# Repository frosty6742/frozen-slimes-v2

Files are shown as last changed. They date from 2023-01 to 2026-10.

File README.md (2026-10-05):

# Frozen Slimes V2

Contact: artemis8615

Check out the [Discord](https://discord.gg/vhHEsKjWGV)

This project uses a Wemo D1 mini, mpu6050, bmi160 or bno085s, and a TP4056 charger. On my personal slimes I wanted to use a 18650 batteries due to the longer battery life and how easy they are to get. 

This is the second version of the case with a hotswappable 18650, strap slots build into the pcb and a much improved pcb design. 

This will now also support mpu6050s, bmis160s, and BNO085s all on one pcb with toggles. 

Tested:
- mpu6050 = yes
- bmi160 = yes
- BNO085s = yes

[Build Tutorial](https://youtu.be/H9HIH2EkDvM?si=KdWcgcjPbuMS_1uO)

[Offical Component Guide](https://docs.slimevr.dev/diy/components-guide.html)

## Index
- [Components](#Components)
- [PCB](#PCB)
- [Cases](#Cases)
- [Assembly](#Assembly)
- [Flashing Firmware](#Flashing-firmware)
- [Links](#Links)
- [Community Builds](#Community-Builds)

### Components   
- [TP4056](https://www.amazon.com/HiLetgo-Lithium-Battery-Charging-Protect/dp/B00LTQU2RK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)
- [Wemos D1 Mini](https://www.amazon.com/Organizer-ESP8266-Internet-Development-Compatible/dp/B081PX9YFV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)
- [2in straps](https://www.amazon.com/gp/product/B0C42S3HQC/ref=ox_sc_act_title_1?smid=A29WFRG6NP7W74&psc=1)
- [IMU docs](https://docs.slimevr.dev/diy/components-guide.html)
    - [MPU6050](https://www.amazon.com/MPU-6050-Accelerometer-Gyroscope-Converter-Compatible/dp/B08TH9NH55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)  
    - [BMI160](https://www.amazon.com/UMLIFE-GY-BMI160-Accelerometer-Gyroscope-Acceleration/dp/B09BQTP8SN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)
- [Switch](https://docs.slimevr.dev/diy/components-guide.htmll)
    - [SS22F32](https://www.amazon.com/uxcell-Vertical-Switch-Terminals-Latching/dp/B07GSGJ6DM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)
- [Battery](https://docs.slimevr.dev/diy/components-guide.html)
    - [18650](https://www.amazon.com/s?k=18650&crid=2H65KICLJGU4U&sprefix=18650%2Caps%2C301&ref=nb_sb_noss_1)
- [1n5817 Diode](https://www.amazon.com/100-Pieces-1N5817-Schottky-Rectifier/dp/B079KDQQPD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)
- [180k Resistor](https://www.amazon.com/EDGELEC-Resistor-Tolerance-Resistance-Optional/dp/B07HDFCNXB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)
- [18650 Battery Solderable Holder](https://www.amazon.com/dp/B09N76T4GL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)

### PCB 

This PCB lets every component be soldered on without any extra wires. This includes the diodes and resistor for battery sense and protected charging. 

To order PCBS go to a website like https://cart.jlcpcb.com/quote upload the gerber file zip file and select quanity and color and order. It should autoselect all the other correct options when you upload the gerber file. 

PCB 

PCB 

PCB 



### Cases
Read the cases documentation in [Case STLs](https://github.com/frosty6742/frozen-slimes-v2/tree/main/Case%20STLs)

### Assembly 
Steps 
- [ ] Solder charge board to PCB
- [ ] Solder mpu to PCB 
- [ ] Solder pins from wemo D1 to wemo, set through holes on PCB and solder the pins on the backside of the PCB

- [ ] Add 180K resitor and diodes in the same orientation as the picture 
- [ ] Bridge correct pads to chose imu (for a BNO solder both bridges under its label, for BMI the one bridge under its label, for the mpu6050 no bridges) 
- [ ] Solder on battery holder
- [ ] Solder on switch

- [ ] Check connections with multimeter for contunity 

- [ ] Feel free to reach out to me with any questions 

### Flashing firmware 
Make sure to install the slime vr server with drivers first. 

- [ ] Use this online [firmware flasher](https://slimevr-firmware.bscotch.ca/) with the latest version of main and wemosd1mini.

Make sure to chose the correct imu and orientation. 



BNO/MPU Instructions
- [ ] Orientation:

rotation

BMI Specific Instructions:

- [ ] Orientation:

221204855-9bce6008-605c-4c25-83e0-810afc768479

- [ ] [Calibrate](https://github.com/SlimeVR/SlimeVR-Tracker-ESP?files=1#bmi160) bmis for first use

If the slime vr drivers arent working for you:
- [ ] Uninstall the drivers from device manager 
- [ ] Extract and install [this CH340 driver](https://www.wemos.cc/en/latest/ch340_driver.html)
- [ ] Flash the trackers

### Links
Resources:
- [The Docs (SlimeVR Documentation)](https://docs.slimevr.dev/)
- [Github Repository SlimeVR](https://github.com/SlimeVR/)
- [SlimeVR Discord](https://discord.gg/SlimeVR)

### Community Builds
I love seeing everyone building and using my pcbs, send in your photos if you want them featured!

227595175-0b3c58bc-bebe-40f4-a213-303ace0f15fe



227594965-319fff3d-ec7c-4dd1-b06a-6c97975d8db4





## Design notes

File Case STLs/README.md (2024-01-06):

### Cases

There are a few diffrent cases that have been created. 

I made the two that are listed below but you can also find a variety of other cases and extensions in the #community-cases channel in the discord. 

#V2.1 Snap Case
This case is designed to printed easily. The two halves just snap over the pcb.

This is still in testing and can be found in the discord [here](https://discord.com/channels/1032474370628653137/1032474371257810986/1186046022753992724)

#V2 Case
This is the original case that I created for the project but some people have trouble printing it and putting it together. 

CAD [here](https://a360.co/42u5nMa).

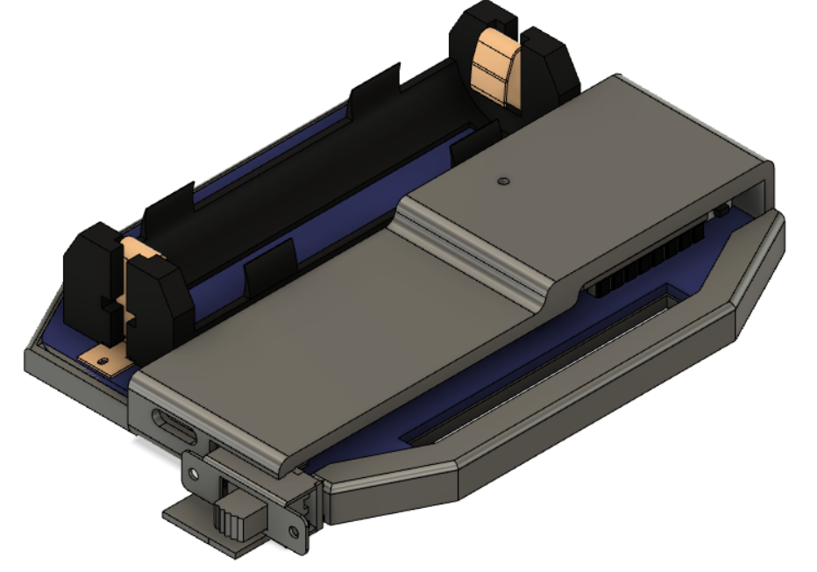
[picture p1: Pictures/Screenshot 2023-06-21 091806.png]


There are some varisous versions of the cases:

**Electronics Cover** - This is the part that slides over the top of the tracker to protect the electronics
- [ ] ECover.stl (This option has the switch soldered to the switch pads)  
- [ ] ECoverTopSwitch.stl (This option has the switch mounted on the top of the tracker)  

<br />

**Bottom Cover** - This is the part that hooks under the tracker to protect the connections
- [ ] BottomCover.stl (This is the standard choice, use it if you are directly soldering the switch on)  
- [ ] BottomCoverThick.stl (This is a thicker version of the one above, its more rigid but the trackers are bigger)
<br />

- [ ] BottomCoverTopSwitch.stl (Use this if you are mounitng the switch on top of the tracker, if you are using the ECoverTopSwitch.stl)  
- [ ] BottomCoverTopSwitchThick.stl (This is a thicker version of the one above, its more rigid but the trackers are bigger)  

<br />

To install the top cover remove the battery holder and slide it on from the battery side of the pcb to the imu side of the case, resolder on the battery holder. 

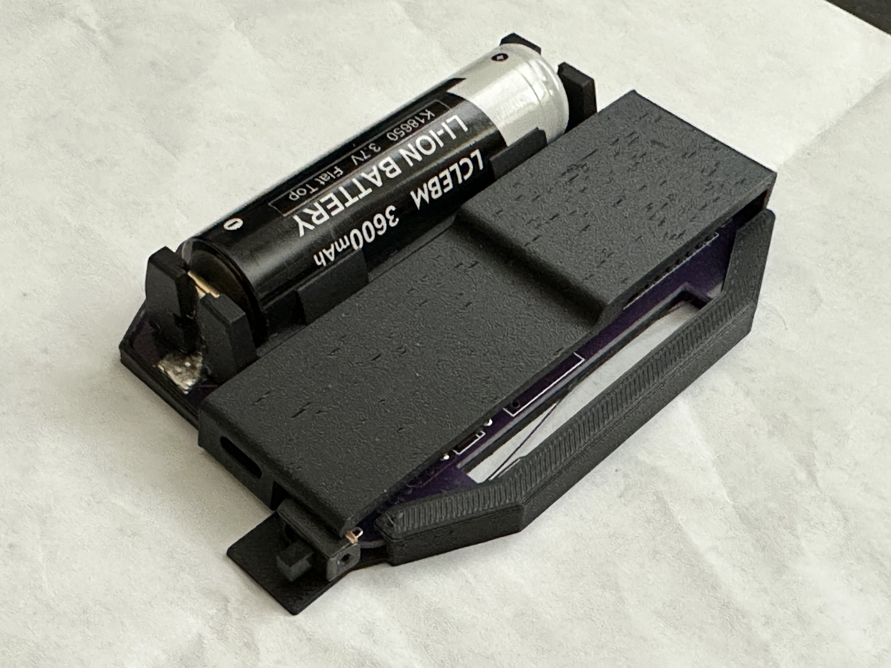
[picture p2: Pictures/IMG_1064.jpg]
 

If you want a case around the extension bmis check out Whitney's artcturus cases and extensions: 
[Arcturus Cases](https://github.com/Lixulia/Arcturus)
 <br />
 
### Printing 


Print in this orientation with NO SUPPORTS. 
20% infill is good.

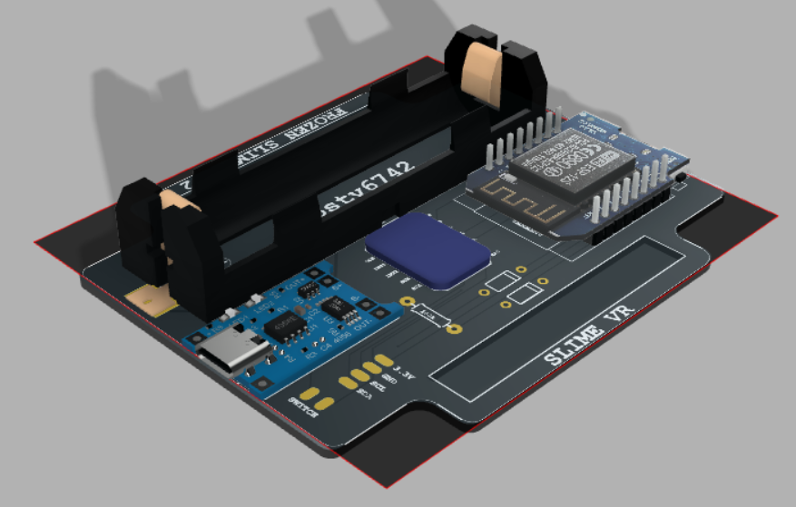
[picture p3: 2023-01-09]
Pictures/render2.png

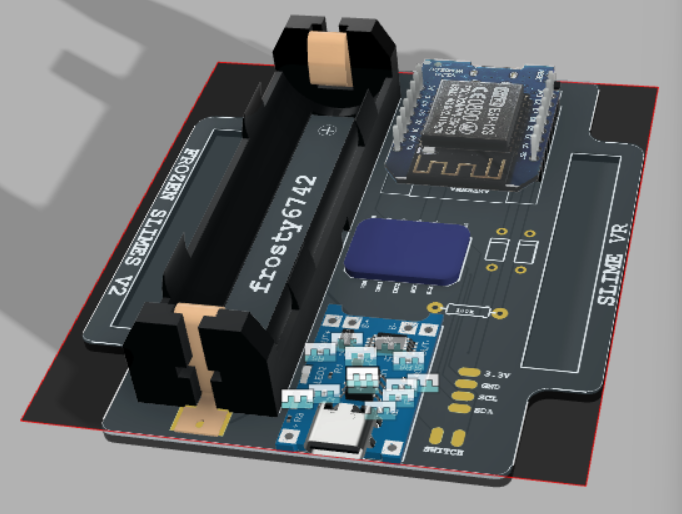
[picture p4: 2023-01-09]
Pictures/render1.png

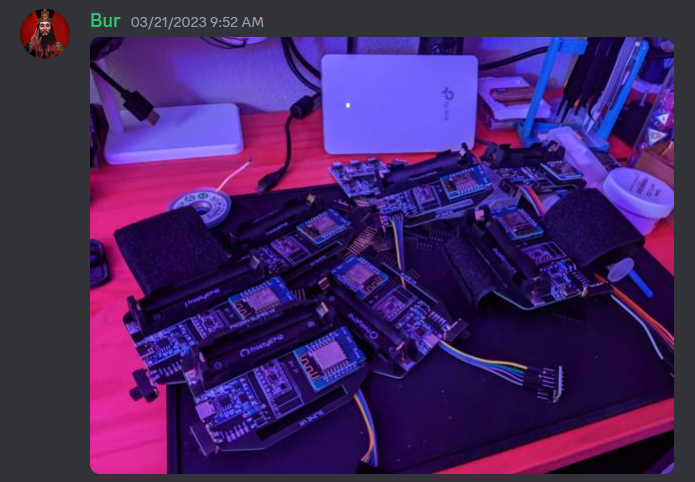
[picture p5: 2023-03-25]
Pictures/227595175-0b3c58bc-bebe-40f4-a213-303ace0f15fe.png

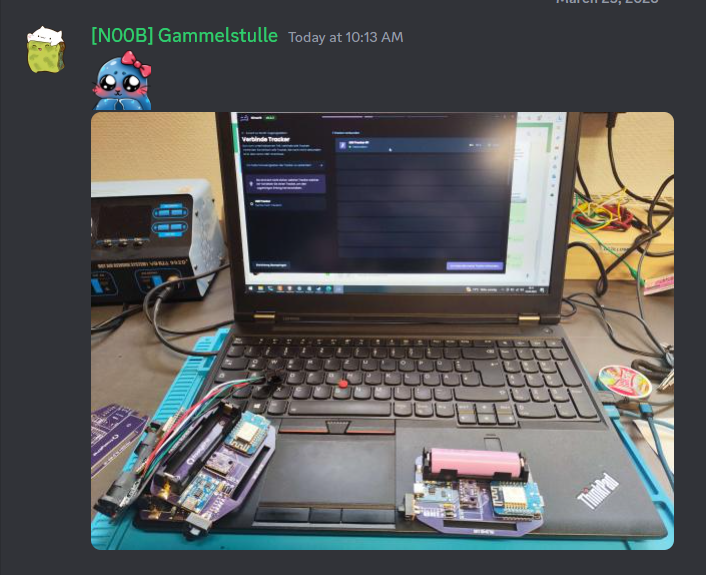
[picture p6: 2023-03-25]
Pictures/Screenshot 2023-03-25 110515.png

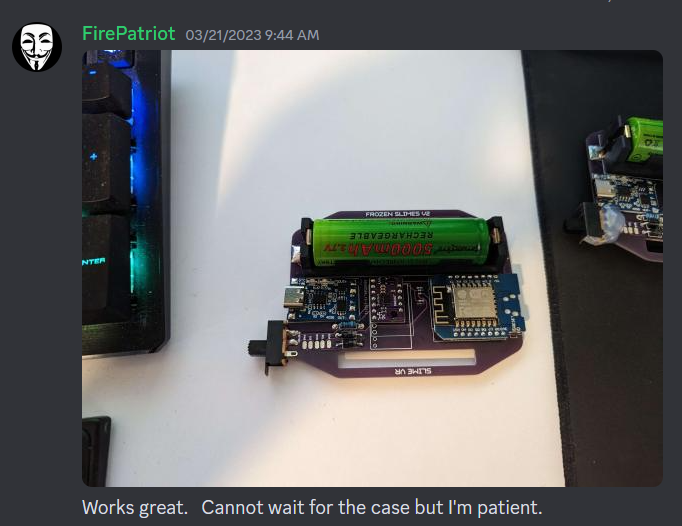
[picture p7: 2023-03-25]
Pictures/227594965-319fff3d-ec7c-4dd1-b06a-6c97975d8db4.png

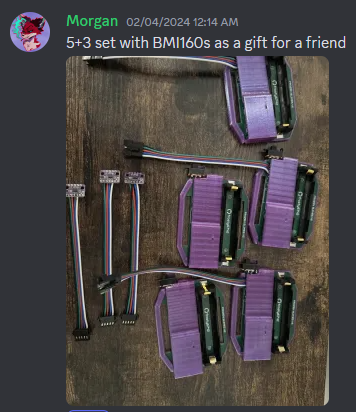
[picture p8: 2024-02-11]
Pictures/Screenshot 2024-02-11 134432453.png

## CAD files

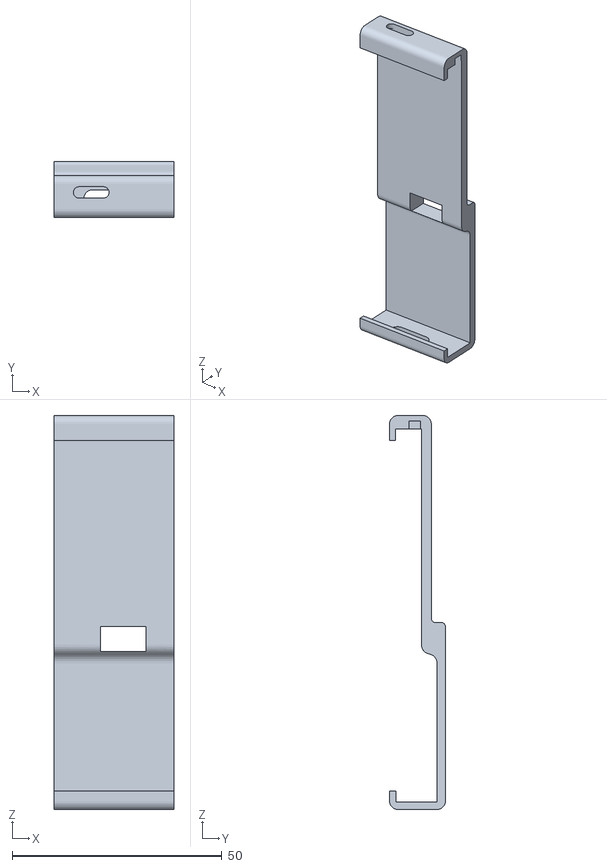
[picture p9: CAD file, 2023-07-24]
Case STLs/ECoverTopSwitch.stl.stl
28.5 x 13.3 x 93.8

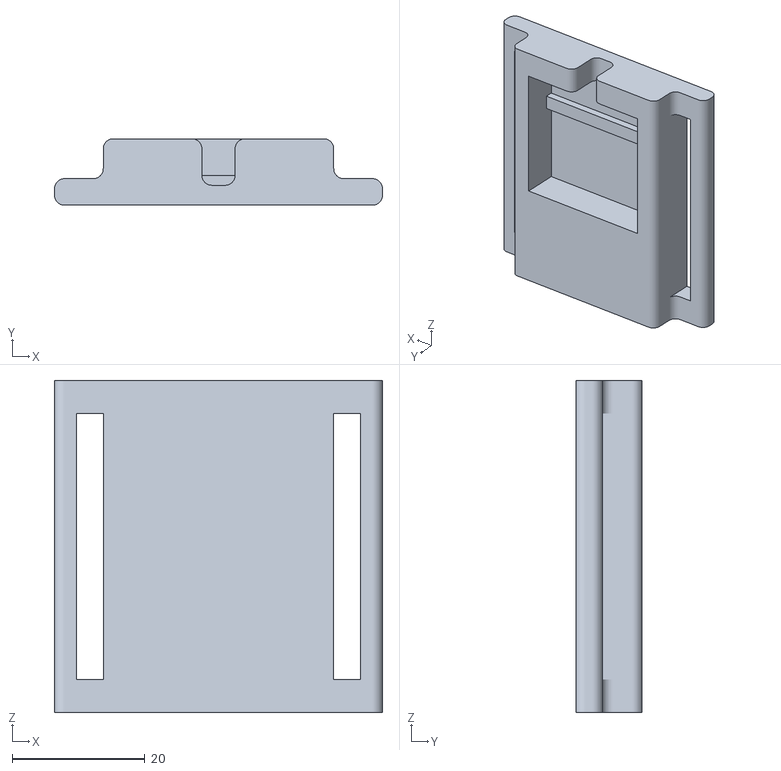
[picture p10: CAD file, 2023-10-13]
Case STLs/Extension Cases/BNO085 Extension Case 0.3mm Tolerance V2 40mm Strap Version Wide Slot.STL
49.3 x 10.0 x 50.0

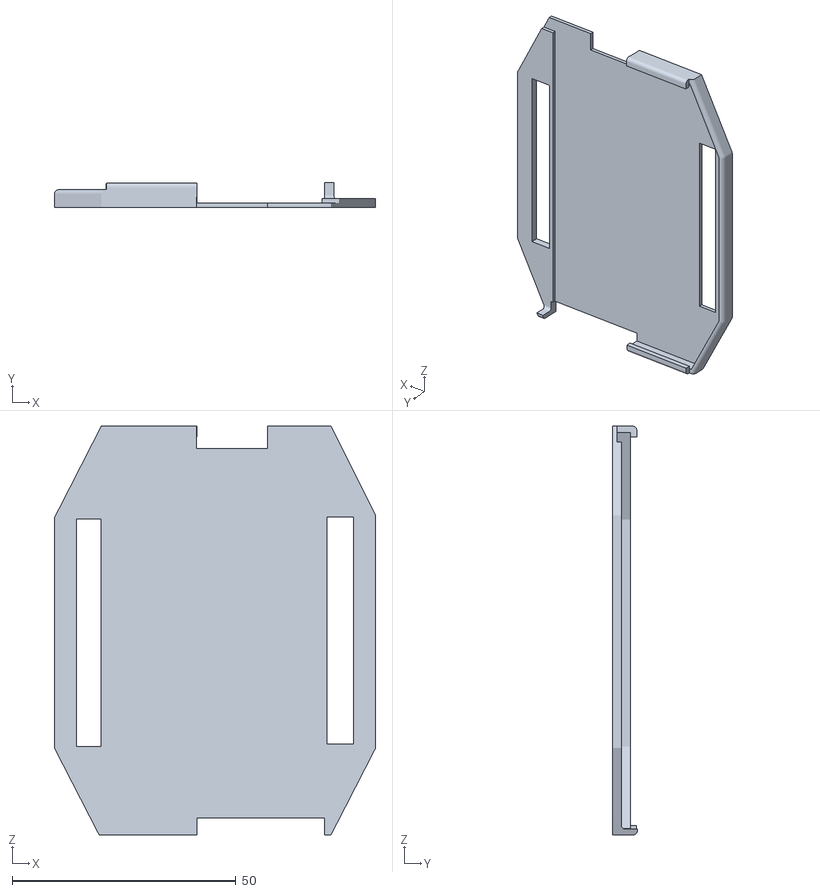
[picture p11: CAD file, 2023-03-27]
Case/BottomShell.stl
71.8 x 5.60 x 91.5

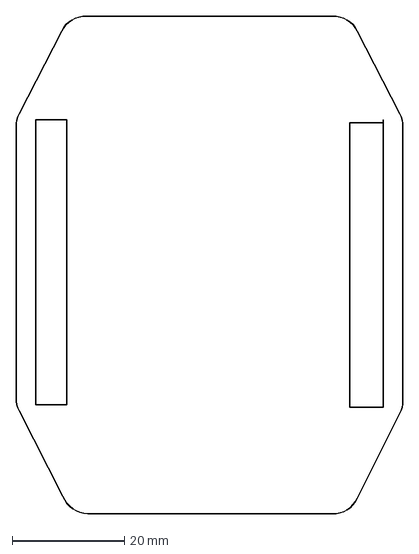
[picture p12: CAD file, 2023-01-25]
PCB/EasyEDA Editable Files/pcbOutLine.dxf
69.0 x 88.8 mm

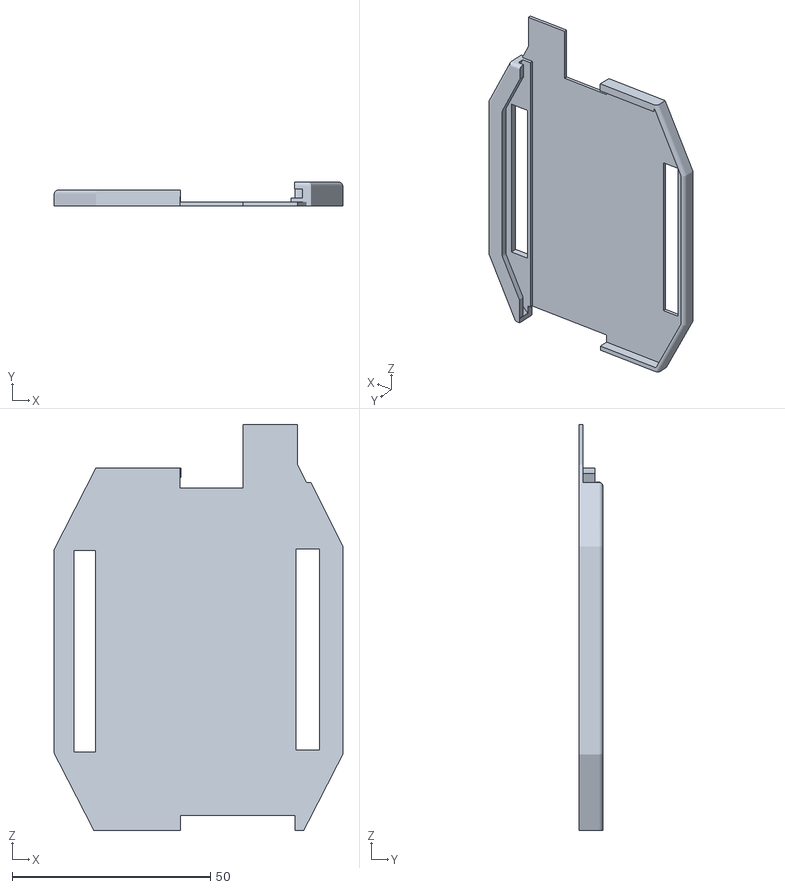
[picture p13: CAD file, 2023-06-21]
Case STLs/BottomCover.stl
72.8 x 6.00 x 102.5

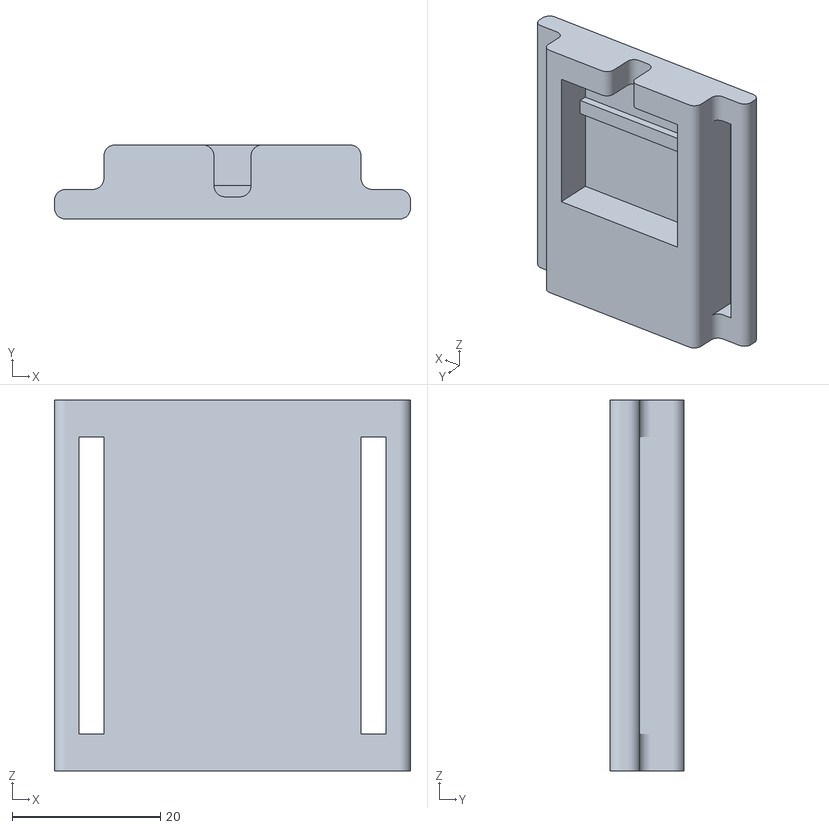
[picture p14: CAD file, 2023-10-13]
Case STLs/Extension Cases/BNO085 Extension Case 0.3mm Tolerance V2 40mm Strap Version.STL
48.0 x 10.0 x 50.0

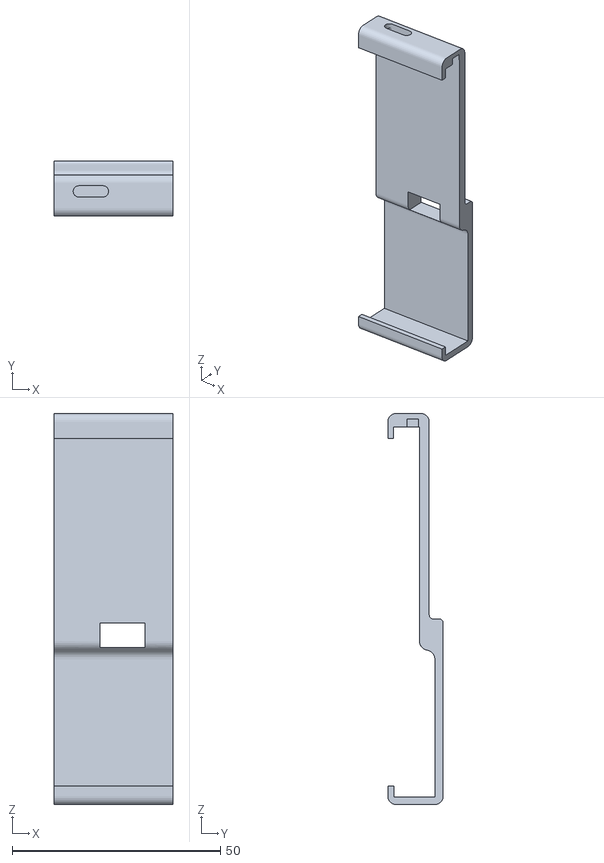
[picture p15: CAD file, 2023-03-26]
Case/ShellTopMount.stl
28.5 x 13.3 x 93.8

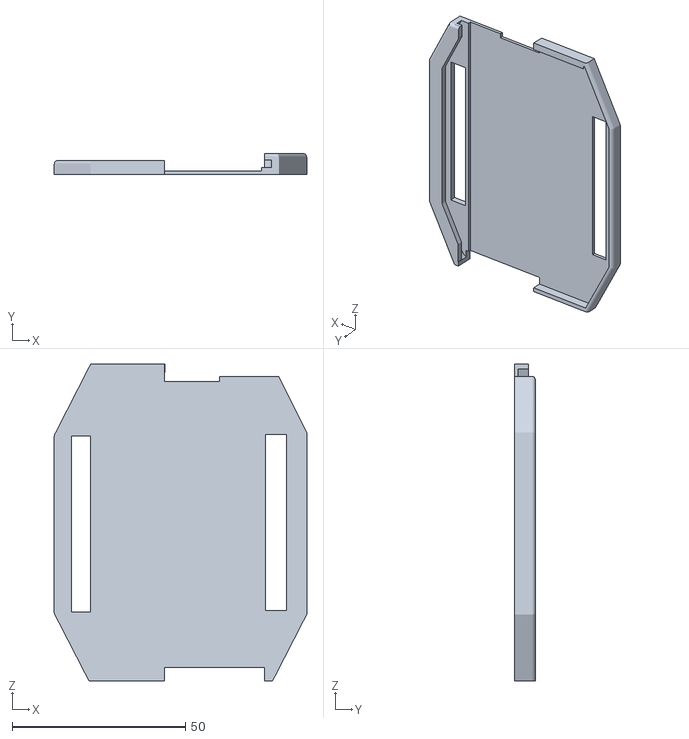
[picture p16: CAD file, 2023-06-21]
Case STLs/BottomCoverTopSwitch.stl.stl
72.8 x 6.00 x 91.5

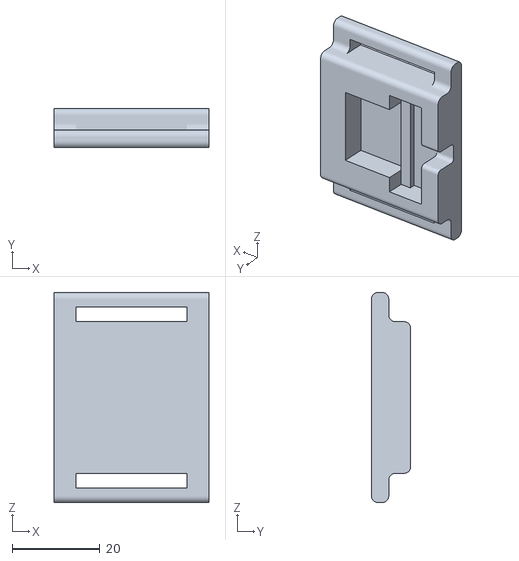
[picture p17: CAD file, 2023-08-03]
Case STLs/Extension Cases/BMI60 Extension Case 0.3mm Tolerance.stl
35.4 x 9.00 x 48.0

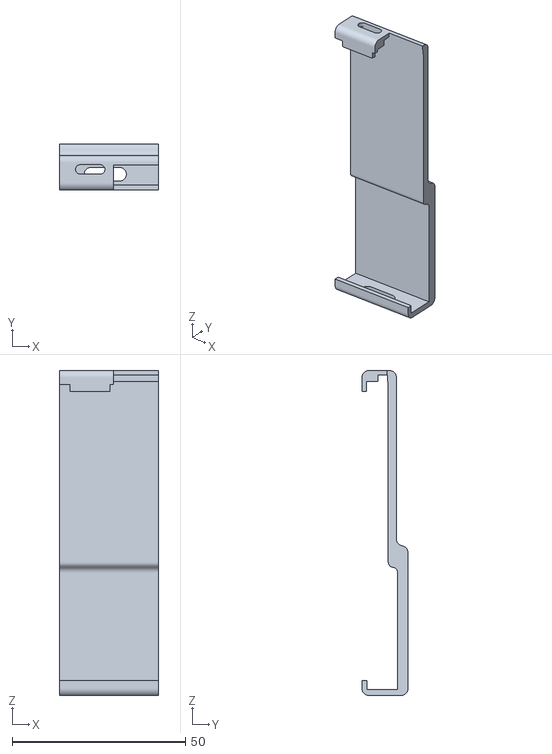
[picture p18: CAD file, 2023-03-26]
Case/ShellSideMount.stl
28.5 x 13.3 x 93.8

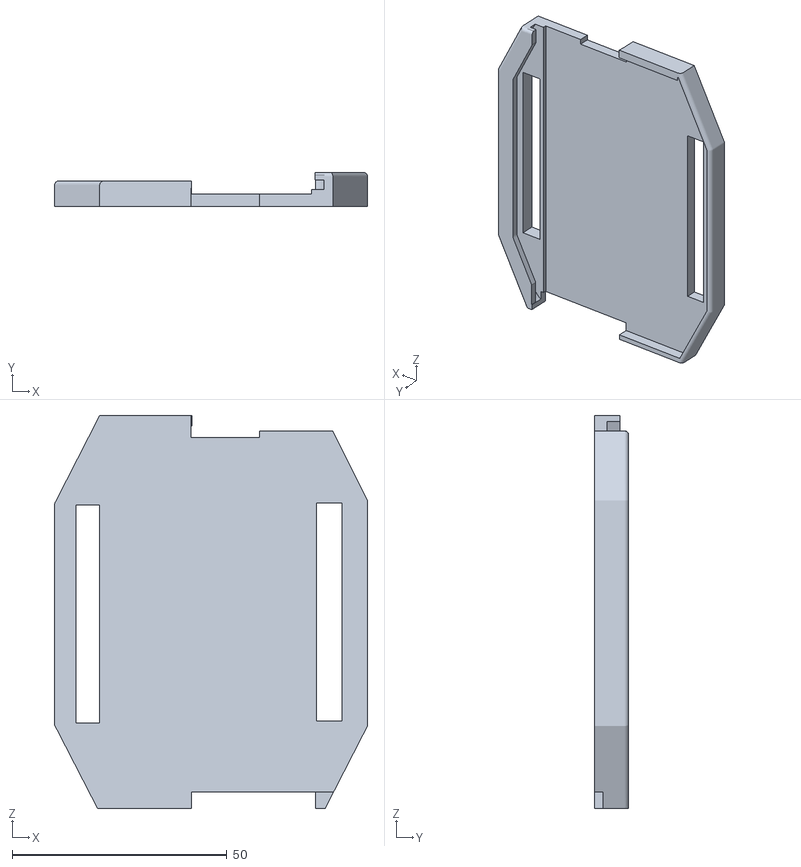
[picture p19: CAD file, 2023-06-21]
Case STLs/BottomCoverTopSwitchThick.stl
72.8 x 8.00 x 91.5

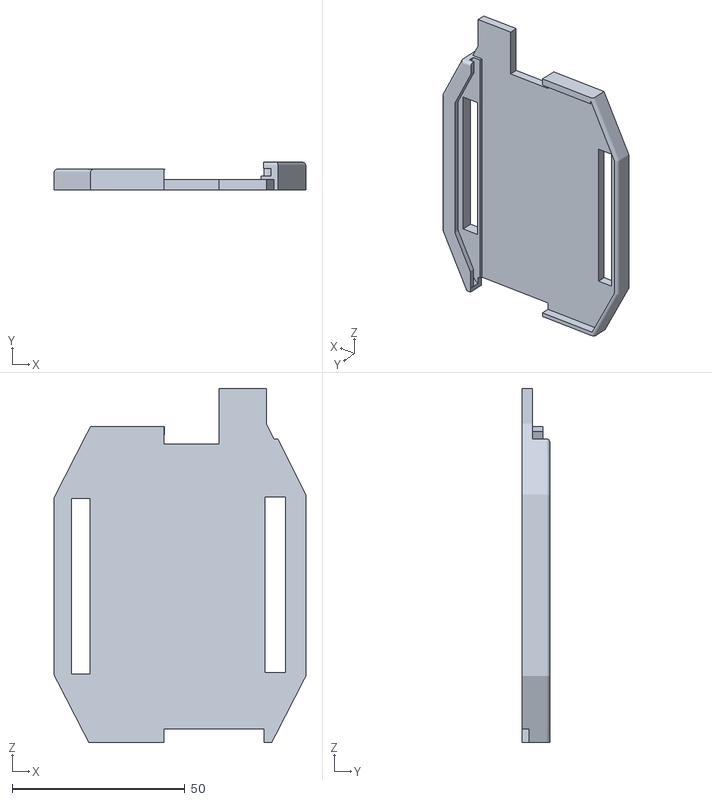
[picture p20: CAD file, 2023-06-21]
Case STLs/BottomCoverThick.stl
72.8 x 8.00 x 102.5

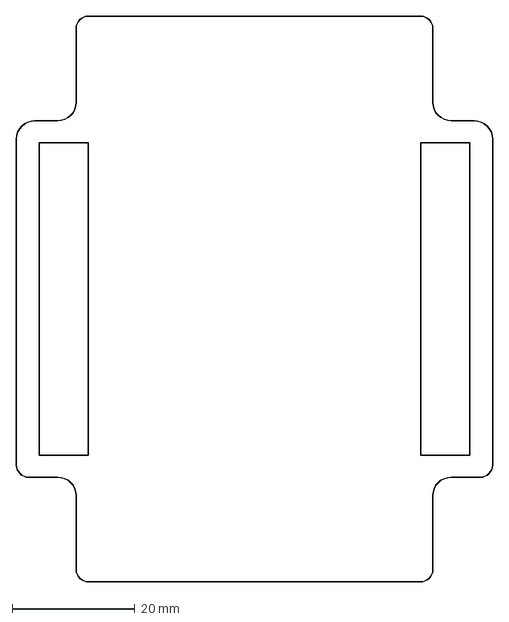
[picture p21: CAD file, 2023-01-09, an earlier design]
PCB/OLD/V2.1 (Old)/pcbOutLine.dxf
77.4 x 92.0 mm

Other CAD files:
Case STLs/Extension Cases/BNO085 Extension Case 0.3mm Tolerance V2.stl
Case STLs/ECover.stl

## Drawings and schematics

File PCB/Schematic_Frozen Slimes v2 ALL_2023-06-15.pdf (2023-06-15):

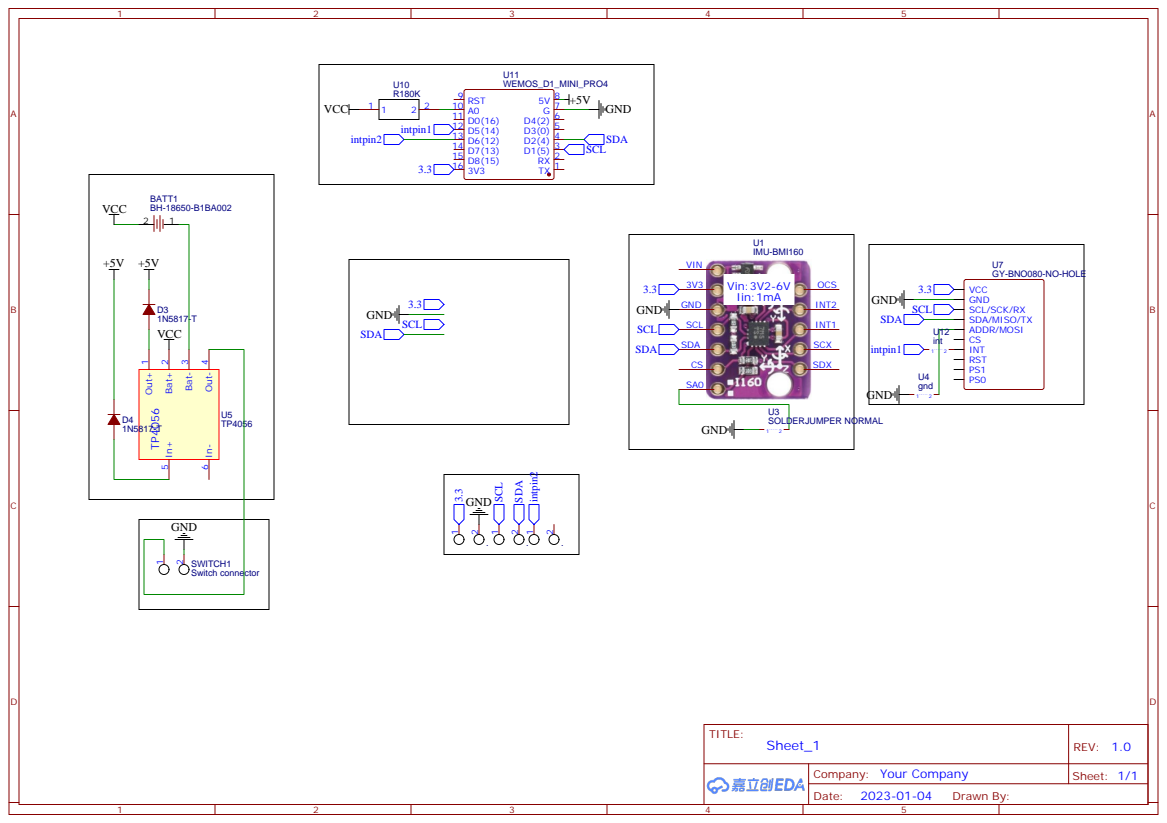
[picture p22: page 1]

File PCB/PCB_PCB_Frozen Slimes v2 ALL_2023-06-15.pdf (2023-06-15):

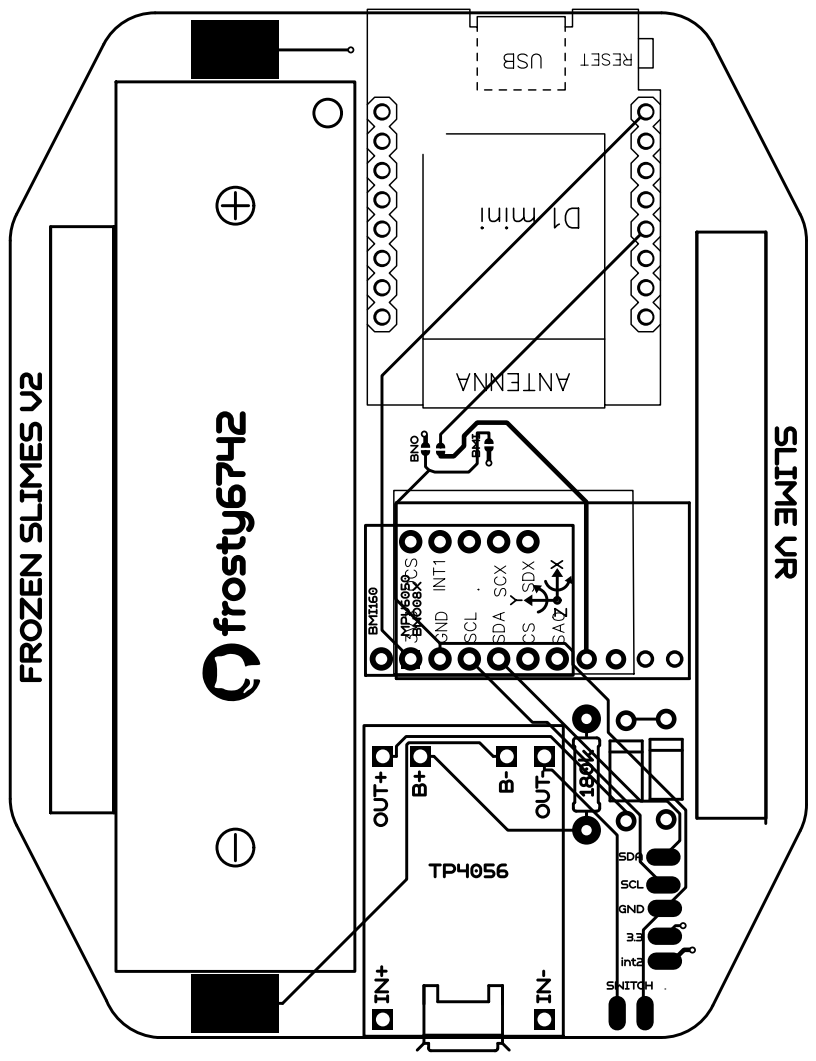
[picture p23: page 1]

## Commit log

2023-01-09 upload mpu
    [pcbOutLine.dxf]
2023-01-10 update pcb fonts
2023-01-25 upload new pcbs
    [pcbOutLine.dxf]
2023-02-08 Upload Tested PCB
    [pcbOutLine.dxf]
2023-03-21 Create Frozen Slimes V2 PCB with Components.step
2023-06-13 Update README.md with calibrate link
2023-06-15 Upload PCB PDFS
2023-06-21 Upload New Case STLS
    [BottomCover.stl, BottomCoverThick.stl, BottomCoverTopSwitch.stl.stl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]
2023-08-03 Create BNO085 Extension Case 0.3mm Tolerance V2.stl
    [BNO085 Extension Case 0.3mm Tolerance V2.stl]
2023-08-03 Create BMI60 Extension Case 0.3mm Tolerance.stl
    [BMI60 Extension Case 0.3mm Tolerance.stl]
2023-09-29 CAD Files for extension wich uses 40mm straps insted of 25mm
    [BNO085 Extension Case 0.3mm Tolerance V2 40mm Strap Version.STEP]
2023-09-29 CAD Files for extension wich uses 40mm straps insted of 25mm
    Version with a larger slot for the strap for use with the straps recomended by the slime vr docs
    [BNO085 Extension Case 0.3mm Tolerance V2 40mm Strap Version Wide Slot.STEP]
2023-09-29 Extension wich uses 40mm straps insted of 25mm
    [BNO085 Extension Case 0.3mm Tolerance V2 40mm Strap Version.STL]
2023-09-29 Extension wich uses 40mm straps insted of 25mm
    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
    [BNO085 Extension Case 0.3mm Tolerance V2 40mm Strap Version Wide Slot.STL]
2024-06-27 Clean Old Folders
    [pcbOutLine.dxf]
2024-06-27 Create Gerber_PCB_Frozen Slimes v2 2024-06-27.zip
2026-10-05 Update README to remove case purchase link
    Removed link for purchasing printed cases and added details about the project components and improvements.
